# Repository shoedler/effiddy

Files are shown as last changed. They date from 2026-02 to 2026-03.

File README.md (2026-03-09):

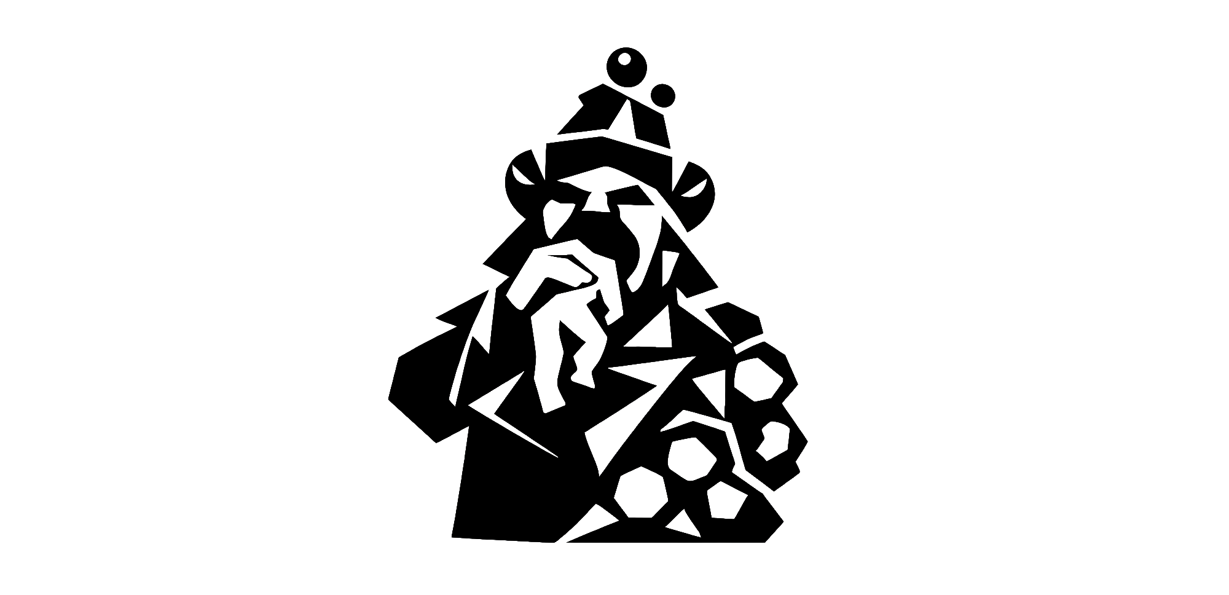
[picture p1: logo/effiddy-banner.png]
Logo: Geometric interpretation of the Kindlifresserbrunnen


# effiddy
A 50-key, column-staggered, wireless split keyboard, inspired by Totem. Designed for Choc-spacing (16.5 by 17.5mm keycaps) and 1350 Choc v1 or v2 switches.


> Kailh Choc v2 Ice Creams, Repo-included 3D printed keycaps

## Effi.. what?
/ˈɛfɪdi/

*effiddy* is a wordplay on **effigy** — a constructed symbolic figure — and *fifty*, referencing the keyboard’s 50 keys.
An **effigy** is a physical representation of an idea, identity, or belief, often ritualistic or iconic in nature.

The design and name are inspired by the **Kindlifresserbrunnen** (Child-Eater Fountain) in Bern, Switzerland:
a striking, unsettling effigy that embodies folklore, symbolism, and cultural memory.
Effiddy adopts this spirit in a minimalist, abstract form — part artifact, part tool.

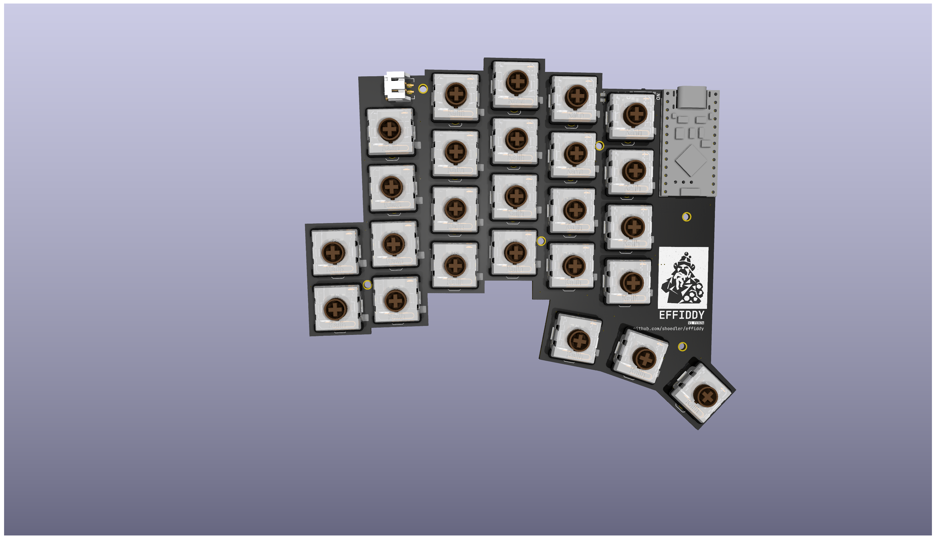
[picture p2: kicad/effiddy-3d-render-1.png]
effiddy PCB render

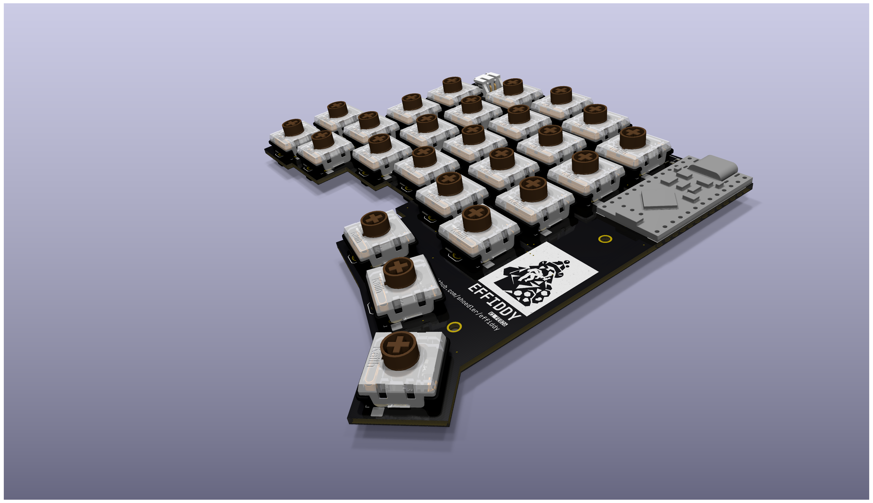
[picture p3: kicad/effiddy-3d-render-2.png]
effiddy PCB render


> **Design note**
> This project came together as a follow up on the [shoedler54](https://github.com/shoedler/shoedler54) split and is also designed entirely in [ergogen.xyz](ergogen.xyz). Since I wanted effiddy to be as thin as possible, I modeled the backside of the case to include cutouts for the SMD components (hotswap sockets, diodes etc.) which resulted in a very thin keyboard, but also an insanely complex ergogen config. The generation of the stl files literally takes minutes when running ergogen through the browser. The reasonable approach to this would've been to use the 3d kicad model of the PCB to model the backplate in CAD. Though, you'd have to model it for both halves due to hotswap socket placement.

## Impressions





---

## Bill of materials

For one complete board - e.g. two halves - you'll need:

- 2 Promicro NRF52840
- 50 1N4148W SOD-123 Diodes
- 50 Kailh Low-profile 1350 Hotswap Sockets
- 50 Keyswitches, Choc v1 or v2
- 50 1u Choc-spaced (16.5x17.5mm) Keycaps, Choc v1 or v2 stem
- 2 EVQPUL02K Switches ($\to$ board reset button)
- 2 SSSS811101 Switches ($\to$ power switch)
- 2 701535 3.7v, 350mAh Batteries
- 2 JST PH 2.0 THT Sockets

For the case you'll need:

- Obviously, the printed case files. See section about printing below.
- 4 M2x3mm heat set inserts.
- 4 M2x6mm (or 8mm) flathead screws
- 8 Stick-on rubber feet

## Build guide

### PCB manufacturing

> PCB related files are located in the `kicad` directory.

I do not suggest rerouting the PCB for fun. There's premade gerber archive located at `kicad/gerber.zip` which you can use. I've used JLCPCB, default settings (1.6mm two layer PCB) and with the black solder mask.

> [!NOTE]
> There's also a 3d render (.stl) of the assembled PCB in the `kicad` directory if you want to model your own case.

### Printing the case

> Case files are located in the `stl` directory.

I used a Babulab A1 mini and default slicer settings (Bambustudio). Everything was printed in their PLA Matte. For a nice effect, I suggest white for the top and keycaps and black for the bottom.

#### What do I need to print?

You'll need at least:

- 2x `effiddy_case_top.stl`, which is the top part of the case where the keyswitches are mounted into - I recommend using the provided 3mf files for that: `effiddy_case_top_left.3mf` and `effiddy_case_top_right.3mf`. Which are mirrored versions with support enabled for the Mcu + Bat enclosures. (Theoretically, bridging works fine, but support is definitely easier and more predictable)
- 1x `effiddy_case_bottom_left.stl`, and
- 1x `effiddy_case_bottom_right.stl`. These are the bottom part of the case - same story, use the provided 3mf files for that: `effiddy_case_bottom_left.3mf` and `effiddy_case_bottom_right.3mf`. These are **not** just mirrored versions. The bottom part of the case is not mirrorable, due to the hotswap sockets being aligned differently for the left and right. 

> [!NOTE]
> The `effiddy_case_bottom_left.stl` and `right.stl` are generated by ergogen. Due to their complexity, they are cursed and a little bit broken. The shape is not closed, there are multiple naked edges, planar and non-planar holes as well as degenerate faces. Despite that, I had no trouble printing it in Bambustudio.

### Printing the keycaps

> Keycap related files are located in the `scad` directory.

The caps require no supports if you place them on one of the fillets - they do however require good bed adhesion. This, just like the case, was also printed on a Bambulab A1 mini with PLA Matte. Also, like the case, I've provided a 3mf file to print regular and indexing (F/J keys on QWERTY) keys. If you have to use the stl directly:

- Use 0.12mm layer height (including the initial layer).
- Use a brim - if your slicer doesn't automatically generate it, add it manually.
- Use a little manually placed support on the face of the keycap. Centered, about 1/3 the way up the slope. In Bambustudio, the slicer will turn this into a small wedge that is just enough to stabilize the cap but not leave any traces of support material on the keycap face.

> [!NOTE]
> The keycap was designed in [OpenSCAD](openscad.org). It's fully parametrized, so it's easy to adapt to your liking.

### Soldering

Since the PCB is reversible it can get confusing quick. All of the components **except the ProMicro and the JST connector** are soldered to the backside of each half.

1. Solder diodes, hotswap sockets, reset- and powerswitches on the backside of each half. **This is also the side were you bridge all of the solder-jumpers with solder** (8 for the Mcu, 2 for the Battery connector).
2. Direct-solder the ProMicro to the frontside of the PCB, along with the JST connector. (Pin Sockets are also an option for the mcu, if you want - it just makes the keyboard a bit thicker)

> [!CAUTION]
> Before you continue it's a good idea to verify that there's no short between the JSTs +/- terminal as well as the ProMicros VCC and GND.

I suggest to load the firmware next and check that everything works before assembly.

### Loading the ZMK firmware

> Firmware related files consist of: config/, boards/, zephyr/ directories, as well as the build.yml file and the GitHub Actions workflow in .github/workflows.build.yml

Get the latest firmware from https://github.com/shoelder/effiddy/actions, select the latest run and scroll down to Artifacts - you'll be able to download the zip archive from there.

> [!NOTE]
> There'll be two .uf2 files per half in the zip archive - a `de-ch` and an `en` version. This refers to the keycode locale that's been used. I myself require a swiss locale, but, to make the default firmware more useful for more people, I've added an english version too. You can check the keymaps out in the `config/boards/shields/effiddy` directory.

For each half:

1. Plug in the half to your device using a USB cable.
2. Press the reset button twice within 500ms - on my versions of the ProMicro, their red LED breaths gently once you've entered bootloader mode.
3. You'll see a `NICENANO` appear in your device tree. Simply drag and drop the **correct** firmware for the half your working on onto the mcu - it should eject itself automatically once the firmware is flashed.

> [!NOTE]
> If you run into trouble, there's also a `settings_reset` firmware provided in the archive. See [the ZMK troubleshooting guide](https://zmk.dev/docs/troubleshooting/connection-issues#reset-split-keyboard-procedure) on how to flash it.

### Assembly



1. Prep the case tops by installing the two heat set inserts and removing support material. In my case, I have used SMD JST connectors which are a bit too wide for the channel in the case which was resolved with a bit of surgery with a sharp utility knife.
2. Connect the battery. Mount the top case.
3. Install the switches and keys.
4. Flip the whole thing, tuck the battery wires into the channel.
5. Mount the back case half. Install the two screws - done!

---

## References

- Flatfootfox' detailed design guide: https://flatfootfox.com/ergogen-part1-units-points/
- nickcoutsos Keymap-editor: https://nickcoutsos.github.io/keymap-editor/
- nickcoutsos Keymap-layout-tools: https://nickcoutsos.github.io/keymap-layout-tools/
- Joel Spadins zmk-locale-generator for the de-swiss keycode header: https://github.com/joelspadin/zmk-locale-generator
- ZMK guide on how to add a new shield: https://zmk.dev/docs/development/hardware-integration/new-shield
- More of my keyboards:
  - shoedler54 - a cheap 54-key wireless split, inspired by the ZSA Voyager: https://github.com/shoedler/shoedler54

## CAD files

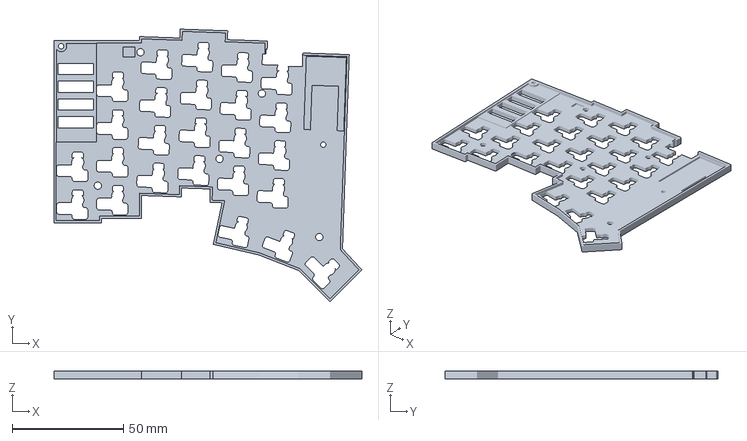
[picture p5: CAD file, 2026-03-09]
ergogen/effiddy_case_bottom_left.3mf
138.5 x 122.7 x 3.60 mm

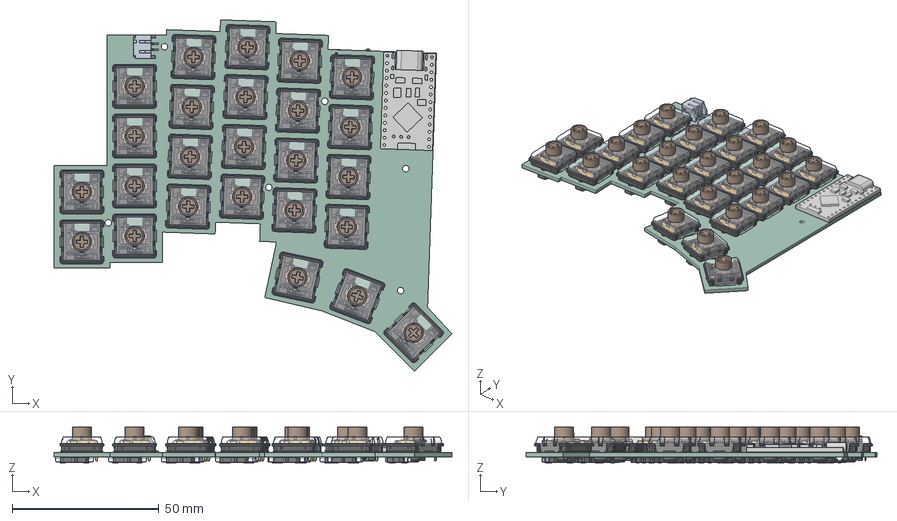
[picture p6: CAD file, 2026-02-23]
kicad/effiddy-3d.step
135.6 x 119.7 x 12.1 mm
SOD123 LF x 25
SOD123 Lower mold x 25
SOD123 Upper mold x 25
evqpu-lc-02k
promicronrf52840
effiddy-3d 1.26
SSSS811101.STEP
pin x 50
socket x 25
bottom x 25
contact x 25
top x 25
stem_tactile x 25
pin1 x 25
pin2 x 25
pin3 x 25
shrunken_spring x 25
effiddy_PCB

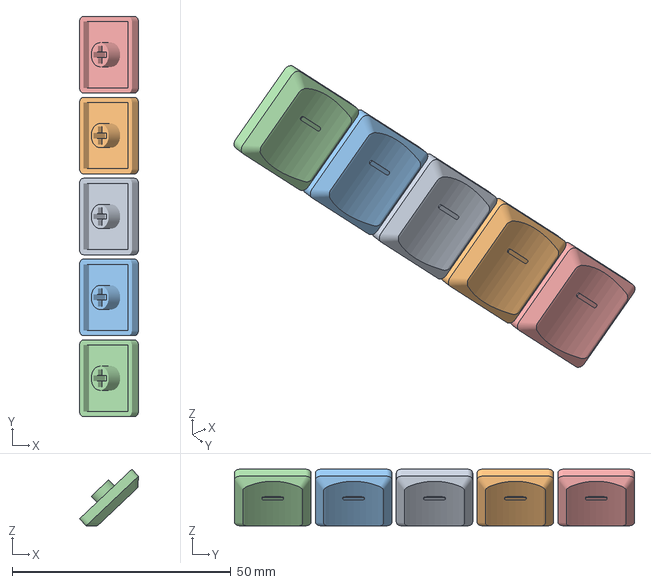
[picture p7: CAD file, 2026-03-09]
scad/keycap_choc-size_mx-stem_homing.3mf
13.5 x 91.5 x 12.9 mm
keycap_choc-size_mx-stem_homing.stl x 5

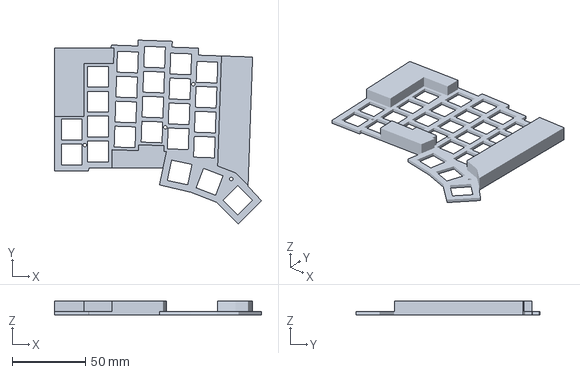
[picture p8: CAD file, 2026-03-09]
ergogen/effiddy_case_top_left.3mf
140.9 x 125.1 x 9.20 mm

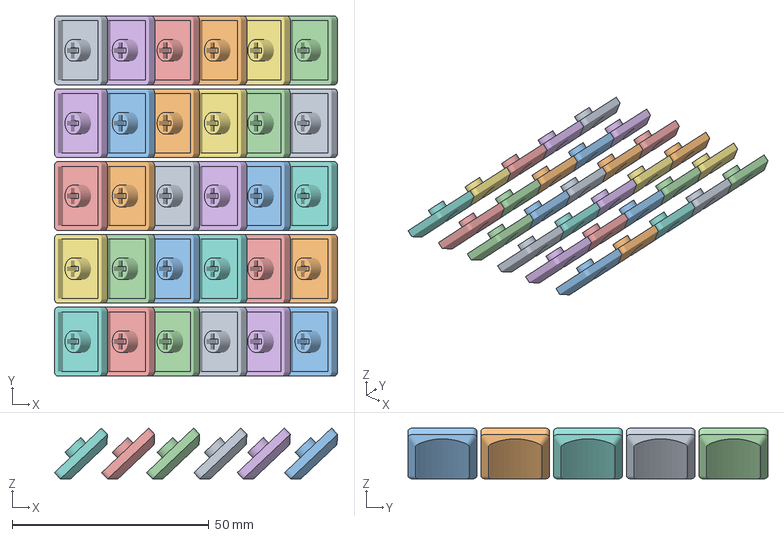
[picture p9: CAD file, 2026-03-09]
scad/keycap_choc-size_mx-stem.3mf
72.0 x 91.5 x 12.9 mm
keycap_choc-size_mx-stem.stl x 30

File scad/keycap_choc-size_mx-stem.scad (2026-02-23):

/*
  Low profile Keycap for MX stems inspired by the ZSA Voyager and Taihao THTs.
  Units: mm

  This has been tested with an FDM 3D-Printer (Bambulab A1 mini) with PLA Matte.
  Requires no supports if you print with a brim and place it on one of its fillets 
  (at an angle)
  0.12mm layer-height (incl. initial layer).

  Notes / modeling choices:
  - Outer body is a two-stage extrusion: straight walls up to `side_fillet_start_z`,
    then a gentle taper toward the top “inset” footprint.
  - The “touch surface” concavity is approximated by subtracting a cylinder-shaped dish,
    with ~`dish_depth` sag at the center.
  - MX cross hole is a 2D plus that gets filleted using offset(r) then offset(-r)
*/

$fn = 96;

// -------------------------
// Parameters (grouped)
// -------------------------
/* Keycap footprint */
cap_w            = 16.5;     // X (use different values for oblong)
cap_h            = 17.5;     // Y
cap_corner_r     = 1.2;    // outer corner radius

/* Vertical dimensions */
cap_thickness        = 4.0;   // total height of cap body (cap bottom to top exterior)
wall_thickness       = 1.2;   // keycap underside cavity walls
underside_pocket_z   = 1.9;   // cavity depth from bottom (inside hollow depth)
side_fillet_start_z  = 2.2;   // z where outer “inset/taper” begins

/* Top inset / touch surface shaping */
inset_lr         = 1.9;   // inset on left/right at the very top (X border)
inset_tb         = 1.9;   // inset on top/bottom at the very top (Y border) (your 2mm->1mm feel)
dish_depth       = 1.0;   // concavity depth at center (approx)
dish_span_scale  = 0.95;  // how wide the dish influences (0..1), smaller = more localized

/* Stem (outer post) */
stem_outer_d     = 5.5;   // outer cylinder diameter
stem_total_len   = 3.8;   // total stem length up to the internal “roof” it attaches to
stem_protrude    = 1.9;   // how much stem sticks out below the keycap bottom (also equals pocket depth)

/* MX cross hole - these values are not to spec, but rather to print nicely. */
mx_plus_size     = 4.1;   // overall height/width of plus (across opposite ends)
mx_leg_thick     = 1.25;  // thickness of each leg
mx_inner_fillet  = 0.3;   // fillet radius for inside corners

/* Homing indicator (optional) */
enable_homing    = false;  // set true for F/J
homing_len       = 5.0;   // bar length (X)
homing_w         = 0.7;   // bar width (Y)
homing_h         = 0.5;   // bar height (Z)
homing_offset_x  = -2;    // move bump toward you (negative X) like typical F/J
homing_offset_z  = 1.1;   // move bump into/away from the keycap

// -------------------------
// Helpers
// -------------------------
module rounded_rect_2d(w, h, r) {
  r2 = min(r, min(w,h)/2);
  offset(r=r2) square([w-2*r2, h-2*r2], center=true);
}

module mx_plus_2d(size, leg, fillet_r) {
  // Sharp plus first
  union() {
    union() {
      square([leg, size], center=true);
      square([size, leg], center=true);
    }

    // Add material only in the 4 re-entrant (inside) corners
    // (these are at ±leg/2, ±leg/2). This won’t touch the 8 outer corners.
    for (sx = [-1, 1], sy = [-1, 1]) {
      translate([sx*leg/2, sy*leg/2]) 
        rotate([0,0,45])
          square(fillet_r, center=true);
    }
  }
}


// capsule-ish bar for homing (2D), then extrude
module capsule_2d(len, w) {
  // hull of two circles to make a capsule
  hull() {
    translate([-(len/2 - w/2), 0]) circle(d=w);
    translate([ +(len/2 - w/2), 0]) circle(d=w);
  }
}

// -------------------------
// Main model
// -------------------------
module keycap_body() {
  // bottom footprint
  base_w = cap_w;
  base_h = cap_h;

  // top footprint (inset)
  top_w  = max(0.1, cap_w - 2*inset_tb);
  top_h  = max(0.1, cap_h - 2*inset_lr);

  // scale factors for the upper taper
  sx = top_w / base_w;
  sy = top_h / base_h;

  lower_h = min(side_fillet_start_z, cap_thickness);
  upper_h = max(0, cap_thickness - lower_h);

  union() {
    // lower straight section
    linear_extrude(height=lower_h)
      rounded_rect_2d(base_w, base_h, cap_corner_r);

    // upper tapered section
    if (upper_h > 0.0001)
      translate([0,0,lower_h])
        linear_extrude(height=upper_h, scale=[sx, sy])
          rounded_rect_2d(base_w, base_h, cap_corner_r);
  }
}

module underside_pocket() {
  // cavity is a rounded rectangle inset by wall thickness
  inner_w = cap_w - 2*wall_thickness;
  inner_h = cap_h - 2*wall_thickness;
  inner_r = max(0, cap_corner_r - wall_thickness);

  // pocket cut from the bottom upward
  translate([0,0,0])
    linear_extrude(height=underside_pocket_z + 0.02)  // tiny extra to avoid z-fighting
      rounded_rect_2d(inner_w, inner_h, inner_r);
}

// concave dish made with a cylinder (axis along X)
module concave_dish_cut() {
  // cylinder gives curvature in Y, leaving X mostly "flat"
  top_h = max(0.1, cap_h - 2*inset_lr);

  a = dish_span_scale * top_h / 2; // half-chord in Y
  h = dish_depth;                  // sagitta (depth)

  // R = (a^2 + h^2)/(2h)
  R = (a*a + h*h) / (2*h);

  // place cylinder so that it cuts depth ~h at center on the top surface.
  // for a cylinder, the surface at y=0 sits at z = zc - R, so set that to cap_thickness - h.
  zc = (cap_thickness - h) + R;

  intersection() {
    translate([0,0,zc])
      rotate([0,90,0])  // axis along X
        cylinder(r=R, h=cap_w*3, center=true);

    // bounding box around the top region
    translate([0,0,cap_thickness - 3*h])
      cube([cap_w*2, cap_h*2, 6*h], center=true);
  }
}


// stem placement and extrude it to connect to keycap hull
module stem_post_with_mx_hole() {
  // force stem top to meet the "roof" (top of the underside pocket) at z = underside_pocket_z
  z1 = underside_pocket_z;
  z0 = z1 - stem_total_len;

  difference() {
    translate([0,0,z0])
      cylinder(d=stem_outer_d, h=stem_total_len);

    translate([0,0,z0 - 0.2])
      linear_extrude(height=stem_total_len + 0.4)
        mx_plus_2d(mx_plus_size, mx_leg_thick, mx_inner_fillet);
  }
}


module homing_bump() {
  if (enable_homing) {
    // put it on the top surface, slightly sunk into the dish cut region.
    translate([homing_offset_x, 0, cap_thickness - homing_offset_z])
      rotate([0, 0, 90])
      linear_extrude(height=homing_h)
        capsule_2d(homing_len, homing_w);
  }
}

module low_profile_xm_keycap() {
    union() {
      difference() {
        // main cap shell (solid, then we hollow it)
        keycap_body();
        
        // underside hollow pocket
        underside_pocket();

        // concave touch dish (top shaping)
        concave_dish_cut();
      }
      // stem post attached to the inside roof (top of pocket)
      stem_post_with_mx_hole();

      // optional homing bump 
      homing_bump();
    }
  
}

// -------------------------
// Render
// -------------------------
low_profile_xm_keycap();

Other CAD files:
ergogen/effiddy_case_bottom_right.3mf
ergogen/effiddy_case_top.stl
ergogen/effiddy_case_top_right.3mf

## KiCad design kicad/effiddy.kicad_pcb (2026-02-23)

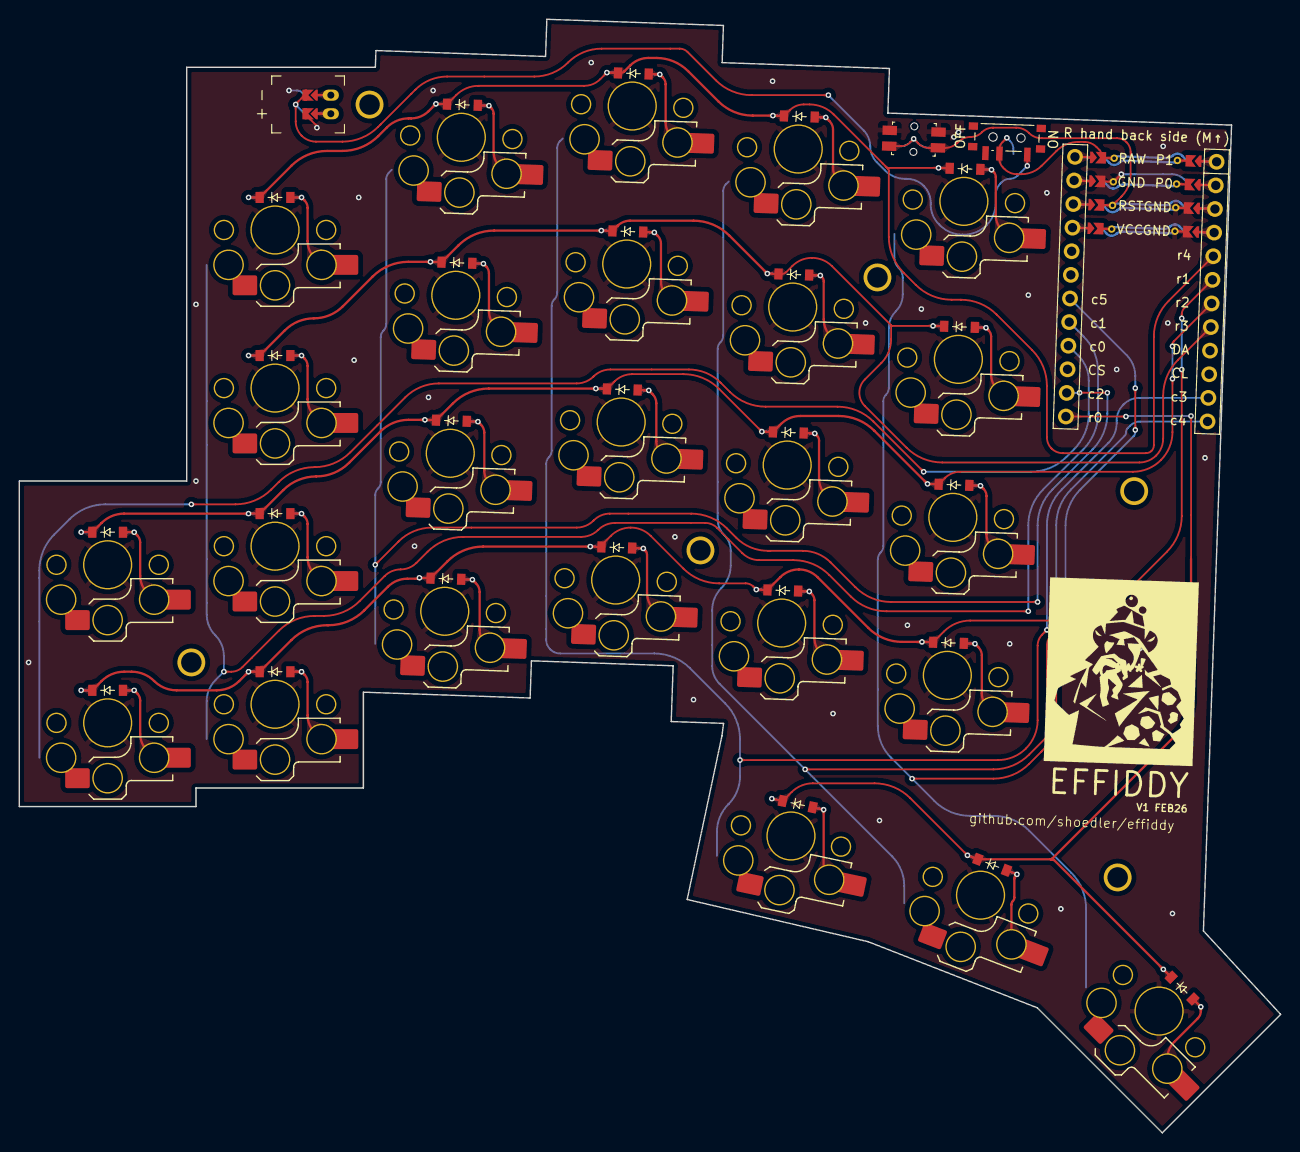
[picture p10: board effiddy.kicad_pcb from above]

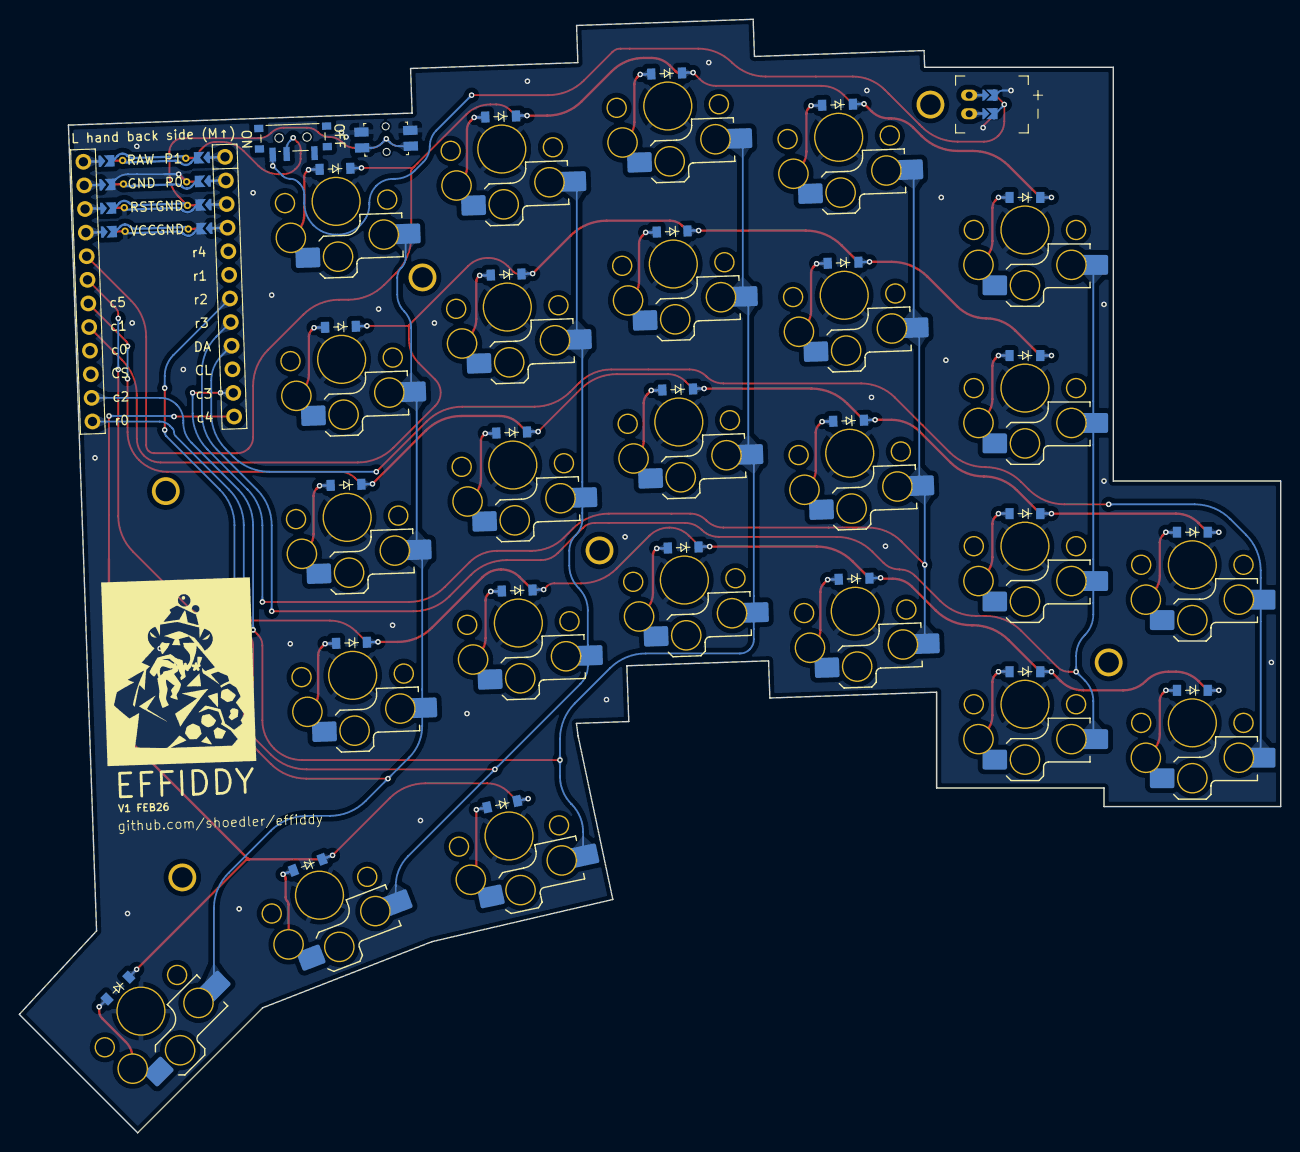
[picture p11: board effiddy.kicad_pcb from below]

Board: 2 copper layers, 135.6 x 119.7 mm, 60 parts (25 on the bottom side), 41 nets.

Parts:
D1, D2, D3, D4, D5, D6, D7, D8, D9, D10, D11, D12, D13, D14, D15, D16, D17, D18, D19, D20, D21, D22, D23, D24, D25: diode_tht_sod123
JST1: battery_connector_jst_ph_2
MCU1: mcu_supermini_nrf52840
MH1, MH2, MH3, MH4, MH5, MH6: mounting_hole_npth
PWR1: power_switch_smd_side
RST1: reset_switch_smd_side
S1, S2, S3, S4, S5, S6, S7, S8, S9, S10, S11, S12, S13, S14, S15, S16, S17, S18, S19, S20, S21, S22, S23, S24, S25: switch_choc_v1_v2

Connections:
GND: JST1.2, MCU1.103, MCU1.104, MCU1.123, RST1.1, RST1.3
JST1_1: JST1.11, JST1.21, JST1.31
JST1_2: JST1.12, JST1.22, JST1.32
RAW: MCU1.124, PWR1.2
RST: MCU1.122, RST1.2, RST1.4
c0: MCU1.16, S1.2, S2.2
c0_r1: D1.2, S1.1
c0_r2: D2.2, S2.1
c1: MCU1.17, S3.2, S4.2, S5.2, S6.2
c1_r1: D3.2, S3.1
c1_r2: D4.2, S4.1
c1_r3: D5.2, S5.1
c1_r4: D6.2, S6.1
c2: MCU1.14, S7.2, S8.2, S9.2, S10.2
c2_r1: D7.2, S7.1
c2_r2: D8.2, S8.1
c2_r3: D9.2, S9.1
c2_r4: D10.2, S10.1
c3: MCU1.11, S11.2, S12.2, S13.2, S14.2, S23.2
c3_r0: D23.2, S23.1
c3_r1: D11.2, S11.1
c3_r2: D12.2, S12.1
c3_r3: D13.2, S13.1
c3_r4: D14.2, S14.1
c4: MCU1.12, S15.2, S16.2, S17.2, S18.2, S24.2
c4_r0: D24.2, S24.1
c4_r1: D15.2, S15.1
c4_r2: D16.2, S16.1
c4_r3: D17.2, S17.1
c4_r4: D18.2, S18.1
c5: MCU1.18, S19.2, S20.2, S21.2, S22.2, S25.2
c5_r0: D25.2, S25.1
c5_r1: D19.2, S19.1
c5_r2: D20.2, S20.1
c5_r3: D21.2, S21.1
c5_r4: D22.2, S22.1
r0: D23.1, D24.1, D25.1, MCU1.13
r1: D1.1, D3.1, D7.1, D11.1, D15.1, D19.1, MCU1.6
r2: D2.1, D4.1, D8.1, D12.1, D16.1, D20.1, MCU1.7
r3: D5.1, D9.1, D13.1, D17.1, D21.1, MCU1.8
r4: D6.1, D10.1, D14.1, D18.1, D22.1, MCU1.5

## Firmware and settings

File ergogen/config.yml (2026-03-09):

meta:
  engine: 4.2.1

units:
  keycap_outline_pad: 2 
  mcu_outline_pad: 0.2

  # Config
  mcu_w: 17.78 # ProMicro width
  mcu_h: 33 # ProMicro height
  bat_w: 16 # Battery width
  bat_h: 41 # Battery height

  switch_dim: 14.2 # +.2 for 3D printing errors
  switchplate_d: 2.2 # 2.2mm thickness for Chocs

  screw_inserthole_r: 1.65
  screw_throughhole_r: 1.2
  screw_standoff_r: 3.1

points:
  key.tags: key
  key.padding: cy
  key.spread: cx
  zones:
    main:
      anchor:
        shift: [150, -150] # Fix KiCad placement
      columns:
        c0: # Outer
          rows.r4: $unset
          rows.r3: $unset
        c1: # Pinky
          key.stagger: 2
        c2: # Ring
          key.splay: -2
          key.spread: cx+.25
          key.stagger: 10
        c3: # Middle
          key.spread: cx+.25
          key.stagger: 4
        c4: # Index
          key.stagger: -4
        c5: # Inner
          key.stagger: -5
      rows:
        r1: # Bottom
        r2: # Home
        r3: # Above
        r4: # Nums
    thumb:
      anchor:
        ref: main_c5_r1
        shift: [-.9cx, -1.05cy]
      columns:
        c3: # Thumb-outer
          key.splay: -10
        c4: # Thumb-middle
          key.spread: 20
          key.splay: -9
          key.origin: [-12, -9]
        c5: # Thumb-inner
          key.spread: 20
          key.splay: -24
          key.origin: [-10, -8]
      rows:
        r0: # Thumb
    mcu:
      key.tags:
        - helper
      anchor:
        - ref: main_c5_r4
          shift: [mcu_w/2+cx/2 + 1.5, -mcu_h/2+cy/2 + .5]
    jst:
      key.tags:
        - helper
      anchor:
        - ref: main_c1_r4
          rotate: 270
          shift: [6, cy/2+5]
    battery:
      key.tags:
        - helper
      anchor:
        - ref: main_c0_r2
          shift: [-0.5, bat_h-cy/2]
    screw_1:
      key.tags: 
        - helper
        - screw
        - pcb_screw
      anchor:
        aggregate.parts:
          - ref: main_c2_r3
          - ref: main_c2_r4
          - ref: main_c1_r3
          - ref: main_c1_r4
        shift: [0, 17]
    screw_2:
      key.tags:
        - helper
        - screw
        - pcb_screw
      anchor:
        aggregate.parts:
          - ref: main_c5_r4
          - ref: main_c5_r3
          - ref: main_c4_r4
          - ref: main_c4_r3
        shift: [0,-2.5]
    screw_3:
      key.tags:
        - helper
        - screw
        - pcb_screw
      anchor:
        aggregate.parts:
          - ref: main_c0_r1
          - ref: main_c0_r2
          - ref: main_c1_r1
          - ref: main_c1_r2
        shift: [0, -3]
    screw_4:
      key.tags:
        - helper
        - screw
        - pcb_screw
      anchor:
        aggregate.parts:
          - ref: thumb_c4_r0
          - ref: thumb_c5_r0
          - ref: main_c5_r1
        shift: [9.5,2]
    screw_5:
      key.tags:
        - helper
        - screw
        - pcb_screw
      anchor:
        aggregate.parts:
          - ref: main_c4_r2
          - ref: main_c4_r1
          - ref: main_c3_r2
          - ref: main_c3_r1
        shift: [0,-3]
    screw_6:
      key.tags:
        - helper
        - screw
        - case_screw
      anchor:
        ref: mcu
        shift: [0, -23]
    screw_7: 
      key.tags:
        - helper
        - screw
        - case_screw
      anchor:
        ref: main_c1_r4
        shift: [-cx-7.5, cy-.8]
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

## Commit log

2026-02-19 Updates pcb with 3d model, updates ergogen config
    [effiddy-3d.step, effiddy.kicad_pcb]
2026-02-19 Moves pcb renders
2026-02-19 Include images of effiddy PCB renders
    Add PCB render images to README
2026-02-21 Adds keycaps
    [keycap_choc-size_mx-stem.scad, keycap_choc-size_mx-stem_25pcs.3mf]
2026-02-23 Refactors PCB 3d view, updates keycap + 3mf file
    [effiddy-3d.step, effiddy.kicad_pcb, keycap_choc-size_mx-stem.3mf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]
2026-03-09 Adds final case files, starts README
    [effiddy_case_bottom_left.3mf, effiddy_case_bottom_right.3mf, effiddy_case_top.stl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]
2026-03-09 Updates case files
    [effiddy_case_bottom_left.3mf]
